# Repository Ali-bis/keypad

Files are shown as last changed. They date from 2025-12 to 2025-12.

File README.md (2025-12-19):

The Void Macro Pad\

This custom 3x3 mechanical keypad was designed to give me a speed boost in Blender and coding. It's built around CircuitPython so I can easily remap the keys without worrying about messing with the code.
My Project Screenshot 1
My Project Screenshot 2
Below is a 3D render showing the PCB mounted inside the proposed 3D-printed enclosure (Outer_Case_1.stl). The board dimensions (approx 100mm x 75mm) are designed to fit flush within the case walls, allowing space for the USB-C connector at the top.
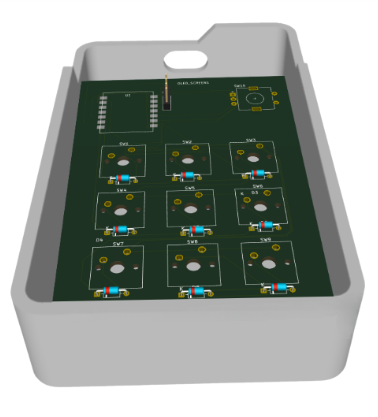
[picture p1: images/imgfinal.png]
My Project Screenshot 3


Why I wanted to build this\

I got tired of having to remember a million key combos for simple tasks like Saving, Undoing, and Rendering. It was really slowing me down. Plus I had a hankering to learn how to design a PCB from scratch using the Seeed XIAO board. (Also, I thought it would be a blast!)

How does it work\

The brain of this operation is a Seeed XIAO RP2040. It's connected up to 9 mechanical switches (I'm a fan of Cherry MX) laid out in a matrix. The details are below...

Firmware: I'm running KMK (CircuitPython keyboard library) to make it all work.\

Features: When hooked up to a computer it's a pretty standard USB HID keyboard. I also snuck in a rotary encoder which lets me control volume and zoom with a nifty little wheel.

The Parts\

Controller: Seeed XIAO RP2040\

Switches: 9 x Cherry MX Blue switches\

Diodes: 9 x 1N4148 (just in case I didn't want to deal with ghosting on my keyboard)\

Encoder: EC11 Rotary Encoder

Status\

The PCB design is done and now I'm just waiting on the boards to arrive. Once they do, I'll be able to pop in some switches and 3D print the case.

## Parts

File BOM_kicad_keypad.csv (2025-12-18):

Reference | Qty | Value | DNP | Exclude from BOM | Exclude from Board | Footprint | Datasheet
D1,D2,D3,D4,D5,D6,D7,D8,D9 | 9 | D_Small |  |  |  | Diode_THT:D_DO-35_SOD27_P7.62mm_Horizontal | ~
OLED_SCREEN1 | 1 | Conn_01x04_Pin |  |  |  | Connector_PinHeader_2.54mm:PinHeader_1x04_P2.54mm_Vertical | ~
SW1,SW2,SW3,SW4,SW5,SW6,SW7,SW8,SW9 | 9 | MX_Switch |  |  |  | Button_Switch_Keyboard:SW_Cherry_MX_1.00u_PCB
SW10 | 1 | RotaryEncoder_Switch |  |  |  | Rotary_Encoder:RotaryEncoder_Alps_EC11E-Switch_Vertical_H20mm | ~
U1 | 1 | XIAO_RP2040 |  |  |  | ali_footprints:XIAO-RP2040-SMD

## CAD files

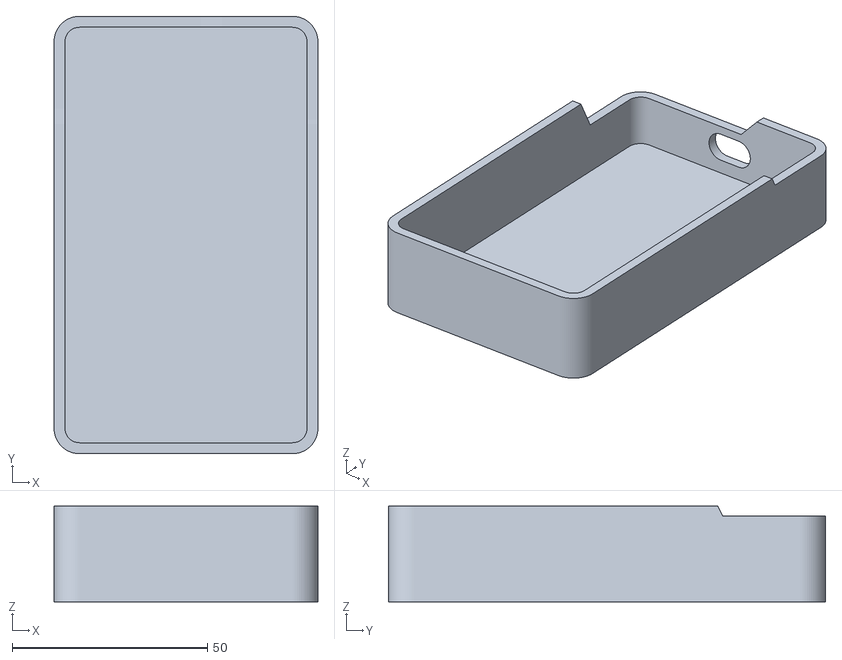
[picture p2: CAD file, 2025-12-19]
cad/Outer_Case_1.stl
67.7 x 112.1 x 24.6

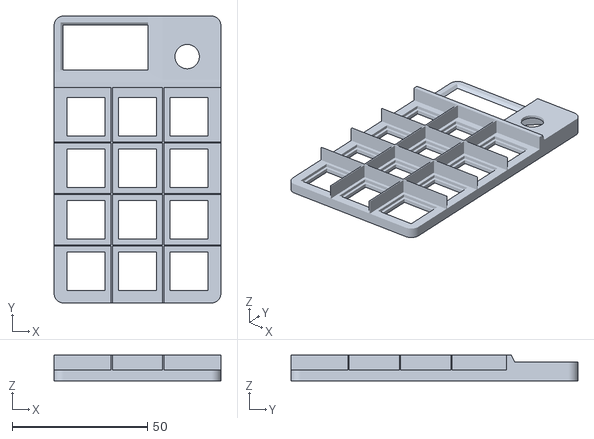
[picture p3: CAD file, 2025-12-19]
cad/Cover.stl
61.7 x 106.1 x 9.45

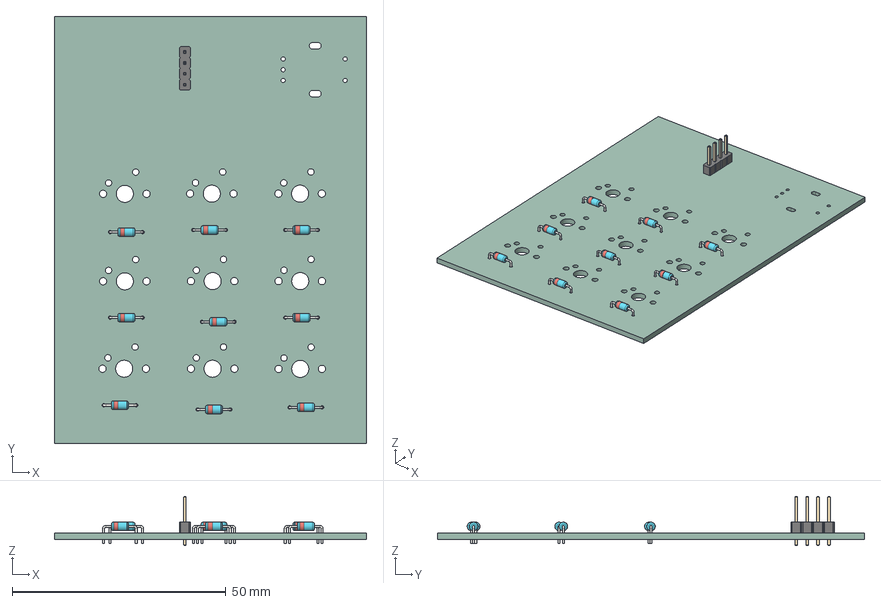
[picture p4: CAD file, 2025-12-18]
cad/kicad_keypad.step
73.0 x 100.0 x 11.5 mm
D_DO-35_SOD27_P7.62mm_Horizontal x 9
PinHeader_1x04_P2.54mm_Vertical
kicad_keypad_PCB

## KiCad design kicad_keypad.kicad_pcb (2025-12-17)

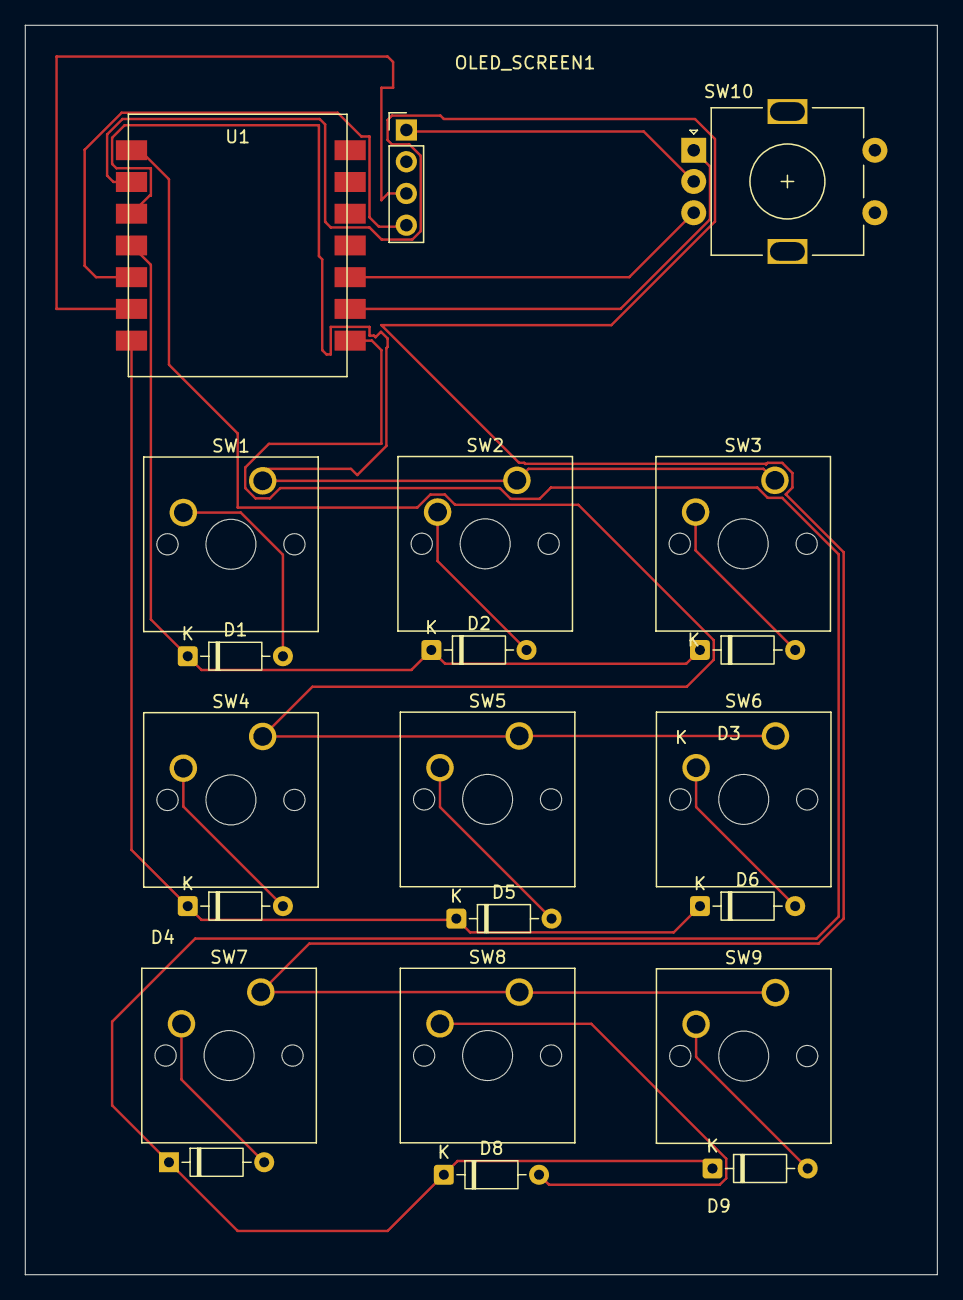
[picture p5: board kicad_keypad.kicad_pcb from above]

Board: 2 copper layers, 73.0 x 100.0 mm, 21 parts (0 on the bottom side), 20 nets.

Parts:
D1, D2, D3, D4, D5, D6, D7, D8, D9: D_Small; D_DO-35_SOD27_P7.62mm_Horizontal
OLED_SCREEN1: Conn_01x04_Pin; PinHeader_1x04_P2.54mm_Vertical
SW1, SW2, SW3, SW4, SW5, SW6, SW7, SW8, SW9: MX_Switch; SW_Cherry_MX_1.00u_PCB
SW10: RotaryEncoder_Switch; RotaryEncoder_Alps_EC11E-Switch_Vertical_H20mm
U1: XIAO_RP2040; XIAO-RP2040-SMD

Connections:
GND: OLED_SCREEN1.1, SW10.C
unnamed: D1.2 (A), SW1.2
unnamed: D1.1 (K), D2.1 (K), D3.1 (K), U1.4 (P3_D3)
unnamed: D2.2 (A), SW2.2
unnamed: D3.2 (A), SW3.2
unnamed: D4.2 (A), SW4.2
unnamed: D4.1 (K), D5.1 (K), D6.1 (K), U1.7 (P6_TX)
unnamed: D5.2 (A), SW5.2
unnamed: D6.2 (A), SW6.2
unnamed: D7.2 (A), SW7.2
unnamed: D7.1 (K), D8.1 (K), D9.1 (K), U1.8 (P7_RX)
unnamed: D8.2 (A), SW8.2
unnamed: D9.2 (A), SW9.2
unnamed: OLED_SCREEN1.3, U1.6 (P5_SCL)
unnamed: OLED_SCREEN1.4, U1.5 (P4_SDA)
unnamed: SW4.1, SW5.1, SW6.1, U1.1 (P0_D0)
unnamed: SW7.1, SW8.1, SW9.1, U1.2 (P1_D1)
unnamed: SW1.1, SW2.1, SW3.1, U1.3 (P2_D2)
unnamed: SW10.A, U1.9 (P8_SCK)
unnamed: SW10.B, U1.10 (P9_MISO)
